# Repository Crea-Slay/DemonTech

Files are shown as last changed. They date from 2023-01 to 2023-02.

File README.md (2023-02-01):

# Introduction

Ce mod pour chaise de bureau est un clone du fameux MonsterTech

Il nécessitera quelques matériaux et/ou peut-être l’achat de machines pour faire les découpes.

Les pièces à découpé sont en HPL de 9mm pour le support chaise et du multiplex 9mm pour les supports joysticks/throttles.

**Attention** : Ce mod fait l’affaire mais n’est pas aussi qualitatif que ceux de MonsterTech. Il y aura un léger battement de gauche à droite. 

# Pré-requis

Pour faire ce mod, vous aurez besoin :

- 1x Planche HPL/Trespa de 8-9mm (idéalement : 40x60 cm)
- 2x Profilé Aluminium 80x40 (23cm) (Attention : ils doivent être taraudé sur un des côtés)
- 2x Profilé Aluminium 80x40 (7cm)
- 2x Equerre 80 rainure T8-10
- ~25 Ecrou avec guidage T8
- ~16 vis M8x 20
- Les vis et écrous correspondant à votre support throttle/Joystick (par exemple : le T16k/visM6, le VKB/vis M5)

Logiciels/Machines :

- Fusion 360 (gratuit)
- CNC avec une fraise de 6 ou 8 mm (voir FABLAB dans votre région)

## (Si pas de CNC)

Peu de gens connaissent le principe de fablab (cf: laboratoire de fabrication).
Pourtant c’est le moyen le plus simple et le moins onéreux pour “produire” une pièce qui n’est pas disponible sur le marché.
A titre d’information, en apportant ma plaque de HPL, il m’a fallu 5min de découpe à la CNC et ptet bien 10-15min de préparation sur le logiciel Fusion 360 (pour rappel, je travaille dans un fablab)

Donc ça peut vous coûter ptet une 20aine d’euros en plus pour faire les découpes.

# 1. Préparation des fichiers à usiner

Maintenant que vous avez vos plaques, il vous faut trouver le modèle 3D.
J’ai répertorié mes fichiers sur un github pour que ce soit plus simple à retrouver :

[https://github.com/Crea-Slay/DemonTech](https://github.com/Crea-Slay/DemonTech)

## Le support de chaise

Sur le site, vous retrouverez les modèles 3D des différents supports de chaises (appelés Form1 à 7).
Pour la majorité des chaises gamings, c’est la Form2 qui est la plus courante. 
(Pour l’instant, seul la Form2 est disponible, mais j’ai récupérer les PDFs avec les cotations des autres formes sur le site de MonsterTech)

Si vous avez une chaise spécifique, vous pouvez aller sur ce lien pour savoir quel forme vous avez besoin :
[https://www.monster.tech/fr/produit/plaque-de-fixation-de-chaise-par-forme/](https://www.monster.tech/fr/produit/plaque-de-fixation-de-chaise-par-forme/)

(généralement, les fablabs et CNC fonctionne avec Fusion360, récupérez le fichier au format .f3d sur le github. Si indication contraire, prenez le fichier au format .stp ou .step )

## Le support Throttle/Joystick

Toujours sur le GitHub, vous retrouverez également les modèles 3D des supports pour votre hotas/hosas en fonction de votre config.
(Pour l’instant, seul le T16k et son throttle TWSC y sont, je rajouterai les autres au fur et à mesures ou à la demande)

# 2. Montage

Quand vous aurez toutes vos pièces, il ne vous restera plus qu’à tout monter sur votre chaise gaming.

1. Coucher votre siège et dévisser les accoudoirs
2. Placer les supports de chaise en desosus des accoudoirs.
(N.B: vous pouvez les mettre entre la plaque de l’accoudoirs et la chaise pour gagner en solidité mais vos accoudoirs seront ptet plus bas. Pour moi qui suit grand, je préfère les laisser dessous que entre)
3. Revisser les accoudoirs.
4. Préparer les profilés. Fixer le petit profilé sur le côté haut du long profilé (partie non-taraudée) avec l’équerre en utilisant les vis M8 et les écrous avec guidage T8. 
5. Placer les profilés de 27cm, côté taraudé contre les supports et les fixer avec les vis M8. (Attention, ne pas serrer SUPER fort au risque de casser le filletage dans le profilé)
6. Mettre les écrous de guidage dans le profilé de 7cm et venir fixer la planche du support Hotas/hosas. 
7. Fixer votre joystick/throttle sur vos planches
8. It’s done !
9. (optionnel : si vous avez trop de flexibilité, vous pouvez ajouter des colsons (serre-cables) autour de vos profilés et les attachés sur les accoudoirs pour gagner en rigidité)

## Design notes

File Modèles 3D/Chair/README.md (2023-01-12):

Guide Form
Support chaise Gaming

Form 1

•	Maxnomic / NEEDforSEAT
•	Noblechairs
•	Secretlab
Et d’autres

Form 2

•	Arozzi
•	AKRacing
•	Boulies
•	Clutch
•	Cougar
•	DXRacer
•	GTOmega Racing
•	Killabee (8XXX Series)
•	L33t (E-Sport/Elite)
•	Sharkoon (Straight Arm Rests)
•	ThunderX3 (Straight Arm Rests)
•	Ulti-Mat
•	Vertagear (Racing)
•	Autres

Veuillez choisir la form 2 pour la majorité des chaises gaming.

Form3

•	IKEA Järvfjället
•	IKEA Matchspel
•	Gamechanger

Form4

•	Backforce

Form5

•	Autonomous ErgoChair 2
•	Autonomous ErgoChair pro

Form6

•	NeueChair
•	Vertagear Trigger

Form7

•	Autonomous Ergochair Recline/Core

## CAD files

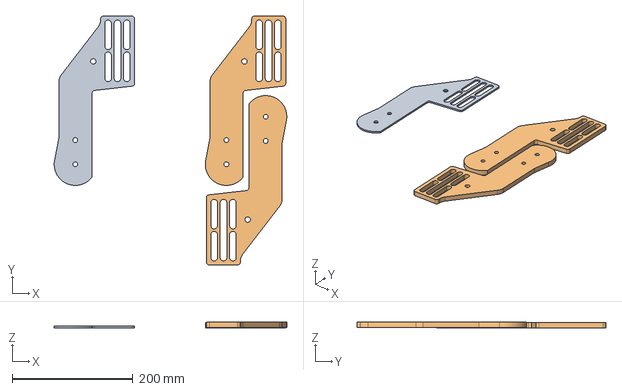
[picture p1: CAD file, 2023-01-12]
Modèles 3D/Chair/Form2/Form2.step
384.9 x 412.0 x 10.0 mm

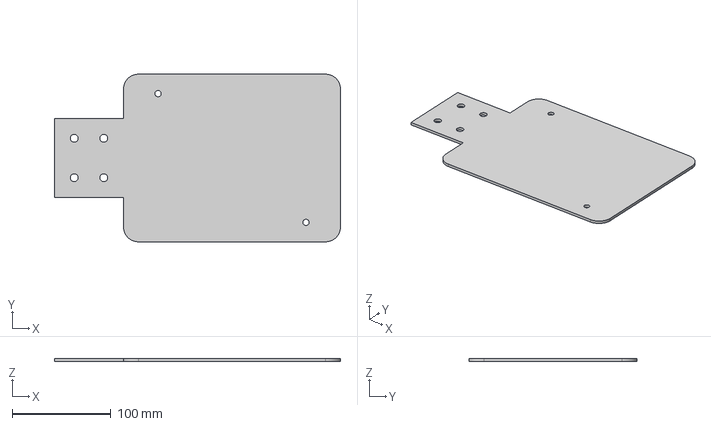
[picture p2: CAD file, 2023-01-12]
Modèles 3D/Hotas/Thrustmaster TWCS/T16000TWCS_Hotas_Support.step.step
290.0 x 170.0 x 3.00 mm

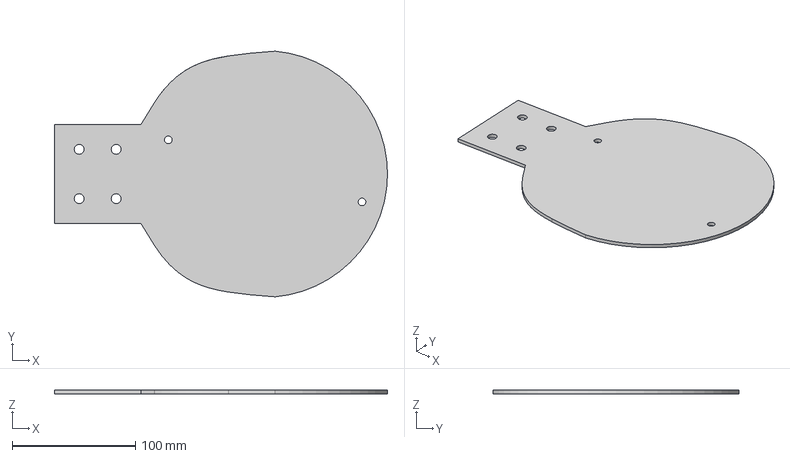
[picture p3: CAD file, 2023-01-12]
Modèles 3D/Joysticks/T16000M FCS/T16000M_Joystick_Support.step
270.0 x 199.2 x 3.00 mm

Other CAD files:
Modèles 3D/Chair/Form2/Support chaise Joystick v4.f3d
Modèles 3D/Hotas/Thrustmaster TWCS/Support Throttle v3.f3d
Modèles 3D/Joysticks/T16000M FCS/DécoupeCNC.f3d
Modèles 3D/Joysticks/T16000M FCS/Support Joystick v4.f3d

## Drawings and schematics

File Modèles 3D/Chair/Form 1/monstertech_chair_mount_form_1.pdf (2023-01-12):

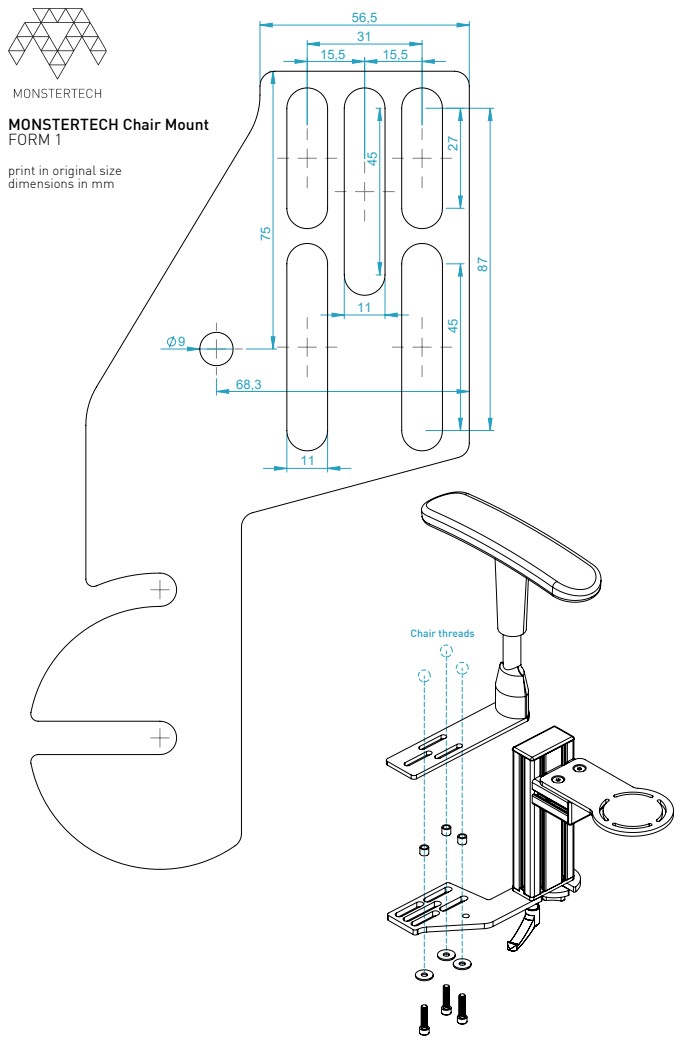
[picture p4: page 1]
Chair threads

MONSTERTECH Chair Mount
FORM 1

print in original size
dimensions in mm

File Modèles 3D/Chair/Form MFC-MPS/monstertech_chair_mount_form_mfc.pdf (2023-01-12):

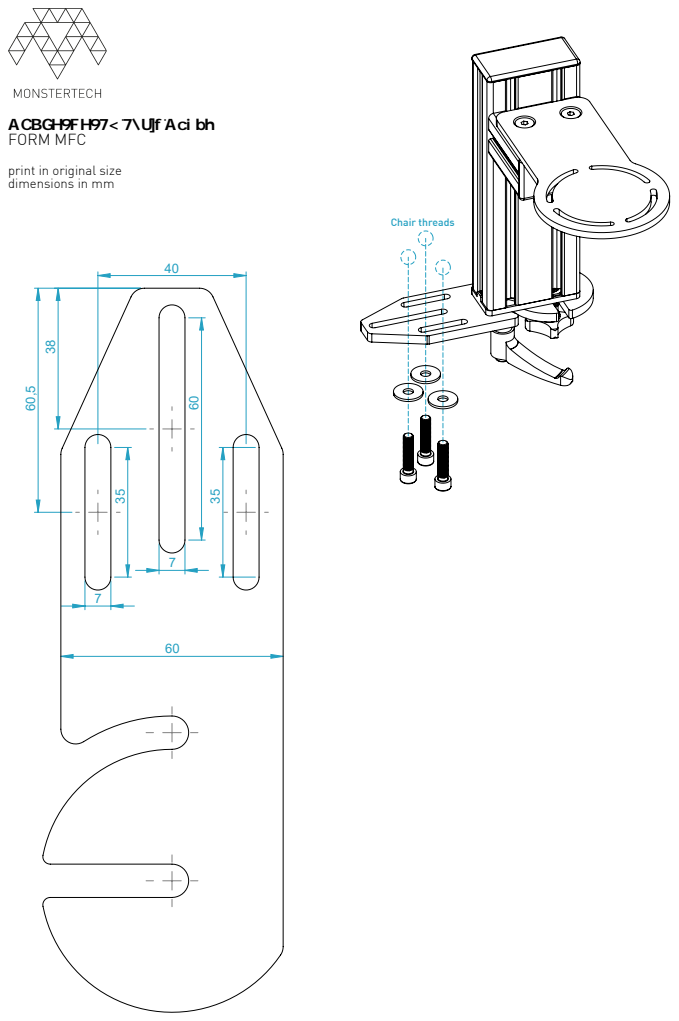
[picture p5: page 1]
Chair threads; FORM MFC

print in original size
dimensions in mm

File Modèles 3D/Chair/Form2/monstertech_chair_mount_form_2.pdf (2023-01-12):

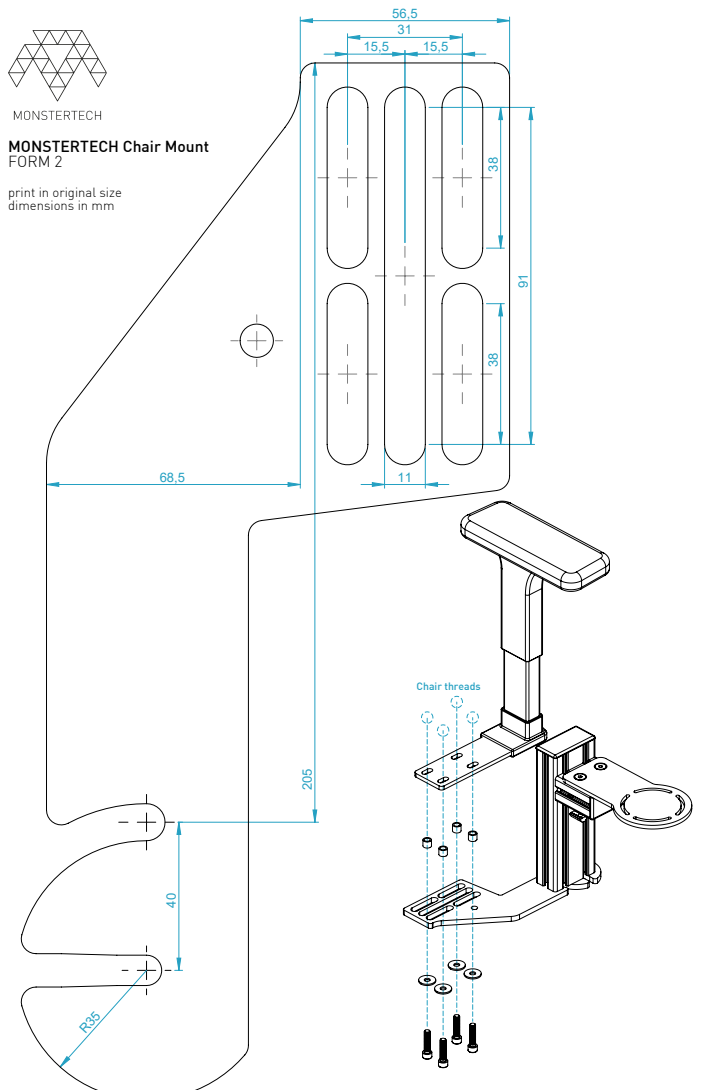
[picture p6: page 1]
Chair threads

MONSTERTECH Chair Mount
FORM 2

print in original size
dimensions in mm

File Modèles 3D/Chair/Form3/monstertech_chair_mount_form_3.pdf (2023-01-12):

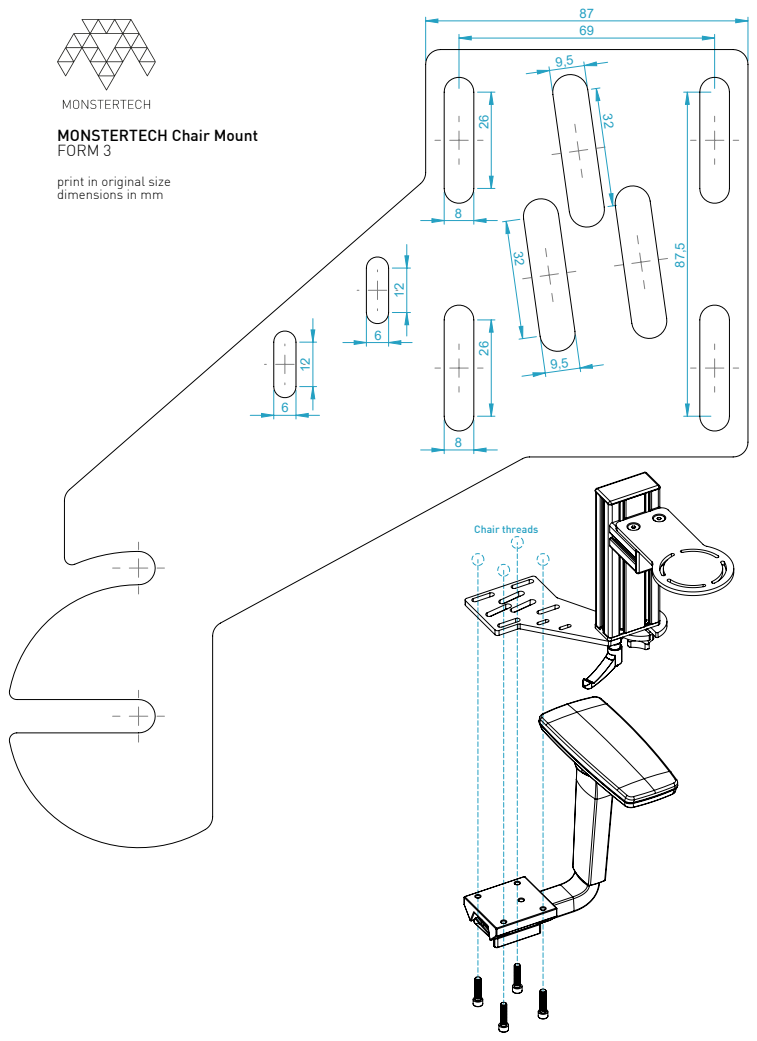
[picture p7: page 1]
Chair threads

MONSTERTECH Chair Mount
FORM 3

print in original size
dimensions in mm

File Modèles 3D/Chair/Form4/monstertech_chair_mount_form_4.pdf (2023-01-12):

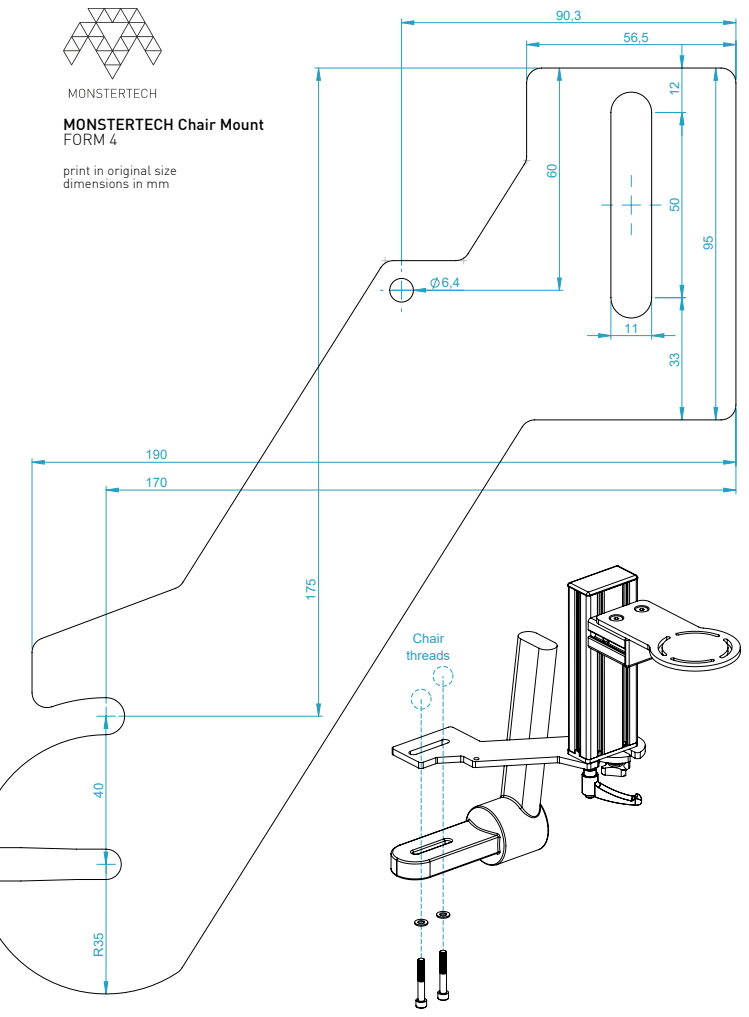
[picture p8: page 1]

MONSTERTECH Chair Mount
FORM 4

print in original size
dimensions in mm

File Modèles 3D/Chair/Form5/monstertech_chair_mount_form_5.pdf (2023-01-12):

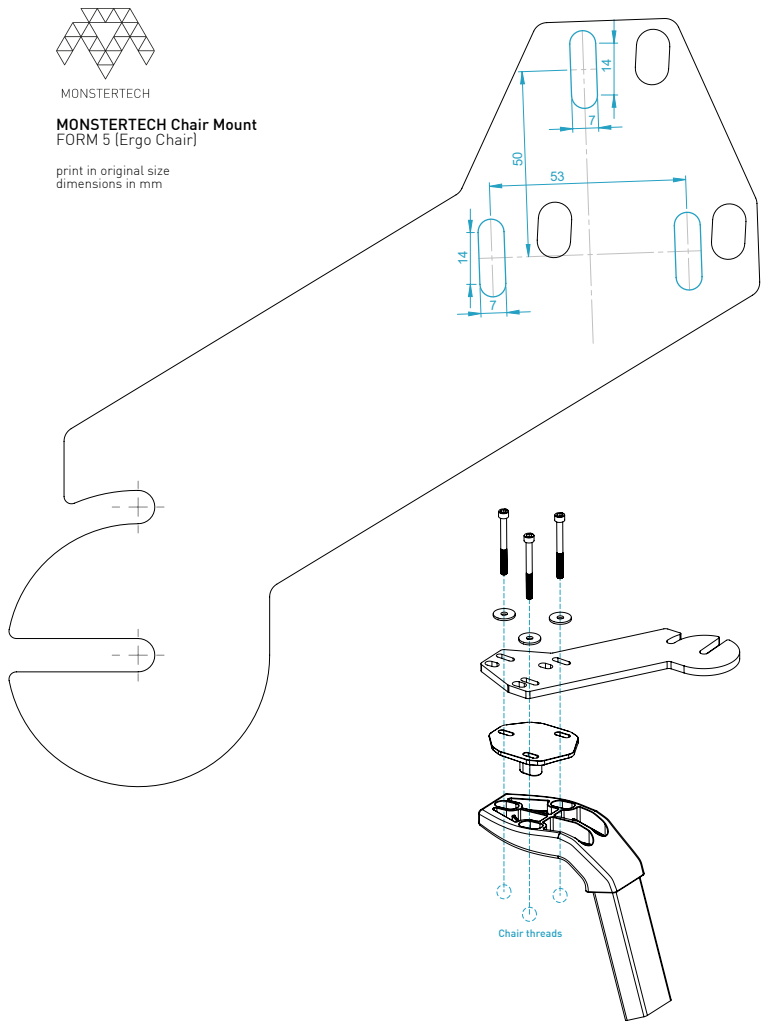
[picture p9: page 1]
Chair threads

MONSTERTECH Chair Mount
FORM 5 (Ergo Chair)

print in original size
dimensions in mm

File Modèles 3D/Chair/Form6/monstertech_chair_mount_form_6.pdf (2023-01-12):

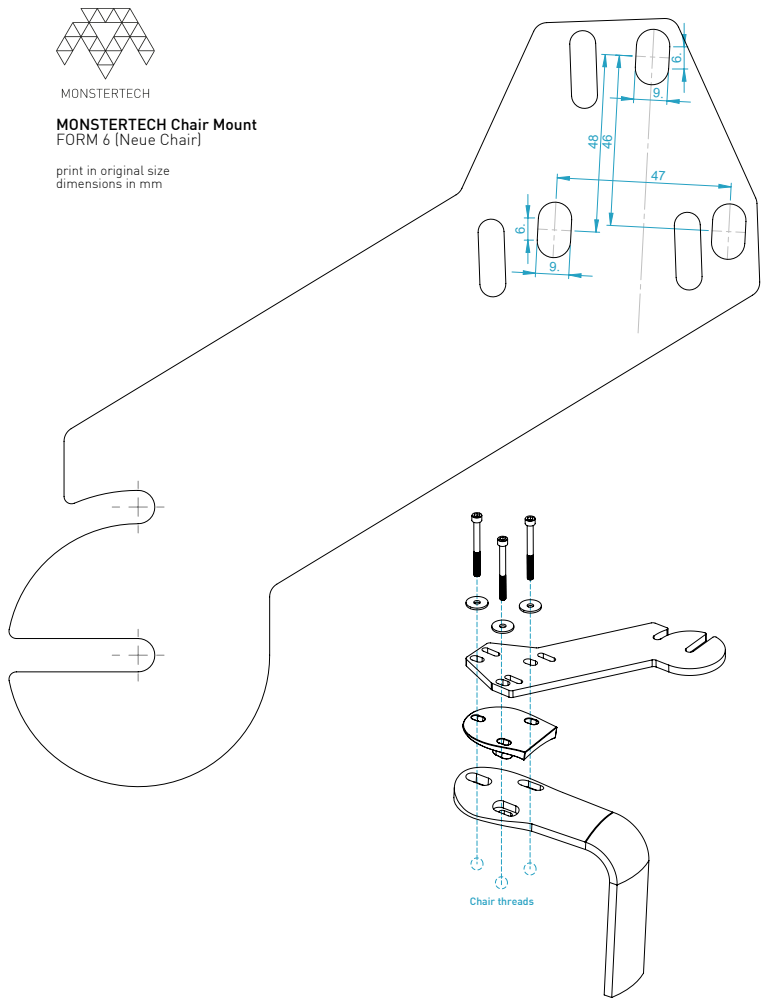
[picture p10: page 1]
Chair threads

MONSTERTECH Chair Mount
FORM 6 (Neue Chair)

print in original size
dimensions in mm

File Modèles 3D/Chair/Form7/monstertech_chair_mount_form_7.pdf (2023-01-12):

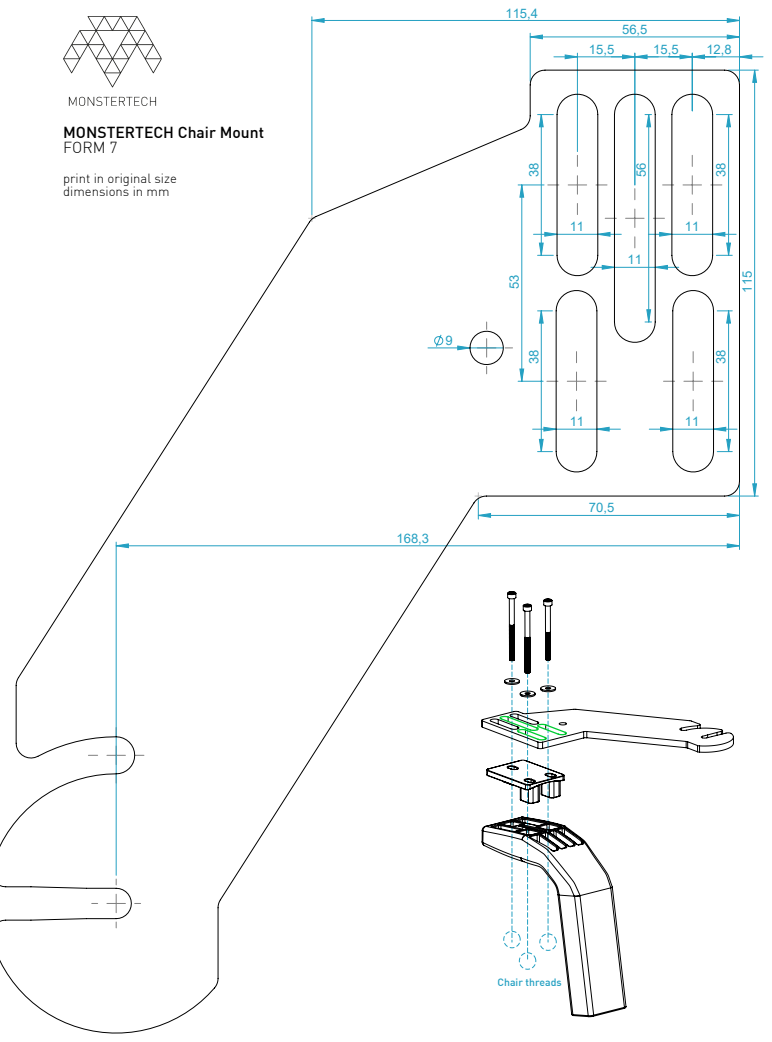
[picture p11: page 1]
Chair threads

MONSTERTECH Chair Mount
FORM 7

print in original size
dimensions in mm

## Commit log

2023-01-12 Remodeling Arborescence folder
    [DécoupeCNC.f3d, Support Joystick v4.f3d, Support Throttle v3.f3d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]
2023-01-12 Adding Step file
    [Form2.step, T16000M_Joystick_Support.step, T16000TWCS_Hotas_Support.step.step]
2023-01-12 Ajout des PDFs
    Cotation des modèles 3D pour les supports de chaises
